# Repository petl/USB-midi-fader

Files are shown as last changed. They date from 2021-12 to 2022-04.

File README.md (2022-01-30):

# USB-midi-fader
A simple to build USB midi controller.

Please note that the V2 of this controller can be bought as a complete set with better components, a pre assembled PCB and much more on my tindie: https://www.tindie.com/products/petl/midi-fader-controller-usb-c/

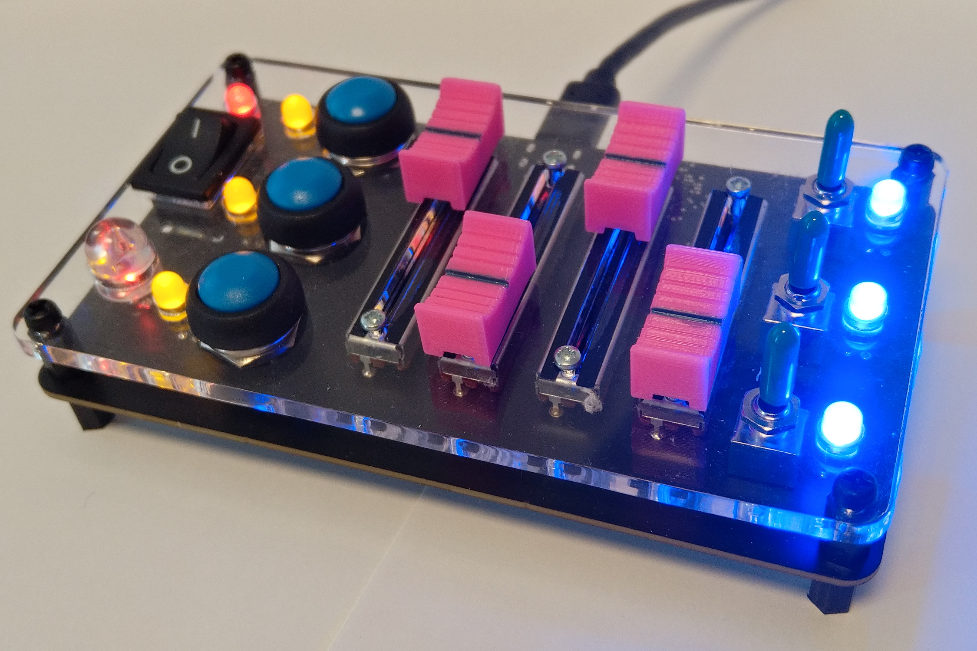
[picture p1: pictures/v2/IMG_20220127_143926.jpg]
<p align="right"> Fader v2.</p>

If you're not interested in that, you can still make everything yourself, all the files (v1 & v2) are open source!

<p><p><h2> Motivation </h2> </p>
I have been browsing the net for an easy to use USB Midi controller which can be used with my mixing software  <a href='https://mixxx.org'>Mixxx</a>  to be able to mix podcasts on the go. Initially I wanted to buy an off the shelf product from Korg, the <a href='https://www.korg.com/de/products/computergear/nanokontrol2/'>Nanokontrol 2</a>, but they raised their prices to 69€. That's honestly not a lot for a product this powerful, but what if I tell you that I can make it at home for less? Let's say 54€ less? Yes, I paid 15€ for the stuff (without the Arduino clone i already had). Read it on my blog <a href='https://quiescentcurrent.com/blog/post.php?p_id=69'>here</a>.<br>

<p align="right"> Finished fader.</p>

<p><h2> Specifications </h2> </p>

The has a few interesting features, mainly that it can easily be programmed in the Arduino IDE. The LEDs are all separately addressable, which makes them writeable via the computer interface. All switches including the big red one are also connected to the <a href='https://www.tindie.com/products/petl/breadboard-arduino-uno-clone//'>Breadboard Arduino clone</a>.  It doesn't need an external power supply or anything else.  
<ul>
<li>4x 30mm Slider Potentiometers with custom knobs. </li>
<li>7x individually addressable LEDs</li>
<li>1x red/green dual color 10mm LED for RX/TX</li>
<li>1x main switch, software controlled.</li>
<li>3x buttons</li>
<li>3x DPST switches </li>
<li>micro USB to serial connection.</li>
</ul> 

<p><h2> Hardware </h2> </p>
The hardware was partly lasercut, and partly 3D printed. The lasercutter is a cheap chinese 40W one with a pair of really expensive <a href='https://www.thorlabs.com/newgrouppage9.cfm?objectgroup_id=762#2534'>thorlabs safety goggles</a>. I used 4mm acrylic glas and grey PLA filament. The fader knobs are pink PLA. <br>
In total the stuff cost me around 15€, including the Arduino clone it would be around 33€. <br><br>

<table class="tg">
<thead>
  <tr>
    <th class="tg-qd3n">Name</th>
    <th class="tg-qd3n">Pcs</th>
    <th class="tg-qd3n">Price</th>
    <th class="tg-78by">Total</th>
    <th class="tg-78by">URL</th>
  </tr>
</thead>
<tbody>
  <tr>
    <td class="tg-lboi">Switch DPST</td>
    <td class="tg-lboi">4</td>
    <td class="tg-lboi">1.29</td>
    <td class="tg-cly1">5.16</td>
    <td class="tg-7h26"><a href="https://www.conrad.at/de/p/tru-components-kippschalter-250-v-ac-2-a-2-x-ein-ein-rastend-1-st-2304637.html">https://www.conrad.at/de/p/tru-components-kippschalter-250-v-ac-2-a-2-x-ein-ein-rastend-1-st-2304637.html</a></td>
  </tr>
  <tr>
    <td class="tg-lboi">Switch red</td>
    <td class="tg-lboi">1</td>
    <td class="tg-lboi">3.3</td>
    <td class="tg-cly1">3.3</td>
    <td class="tg-7h26"><a href="https://www.ebay.at/itm/312093751996">https://www.ebay.at/itm/312093751996</a></td>
  </tr>
  <tr>
    <td class="tg-lboi">Button switch</td>
    <td class="tg-lboi">3</td>
    <td class="tg-lboi">0.59</td>
    <td class="tg-cly1">1.77</td>
    <td class="tg-7h26"><a href="https://www.ebay.at/itm/223587573763">https://www.ebay.at/itm/223587573763</a></td>
  </tr>
  <tr>
    <td class="tg-lboi">Slider Potentiometer</td>
    <td class="tg-lboi">4</td>
    <td class="tg-lboi">0.89</td>
    <td class="tg-cly1">3.56</td>
    <td class="tg-7h26"><a href="https://www.conrad.at/de/p/tru-components-f3031n-schiebe-potentiometer-10-k-mono-0-1-w-linear-1-st-1567032.html">https://www.conrad.at/de/p/tru-components-f3031n-schiebe-potentiometer-10-k-mono-0-1-w-linear-1-st-1567032.html</a></td>
  </tr>
  <tr>
    <td class="tg-lboi">LED 5mm</td>
    <td class="tg-lboi">7</td>
    <td class="tg-lboi">0.02</td>
    <td class="tg-cly1">0.14</td>
    <td class="tg-7h26"><a href="https://www.ebay.at/itm/124214363745">https://www.ebay.at/itm/124214363745</a></td>
  </tr>
  <tr>
    <td class="tg-cly1">LED 10mm</td>
    <td class="tg-cly1">1</td>
    <td class="tg-cly1">1.26</td>
    <td class="tg-cly1">1.26</td>
    <td class="tg-7h26"><a href="https://www.ebay.at/itm/323443837179">https://www.ebay.at/itm/323443837179</a></td>
  </tr>
  <tr>
    <td class="tg-cly1">Resistor 220 Ohm</td>
    <td class="tg-cly1">3</td>
    <td class="tg-cly1">0.07</td>
    <td class="tg-cly1">0.21</td>
    <td class="tg-7h26"><a href="https://www.ebay.at/itm/372813822157">https://www.ebay.at/itm/372813822157</a></td>
  </tr>
  <tr>
    <td class="tg-cly1">Resistor 1k Ohm</td>
    <td class="tg-cly1">6</td>
    <td class="tg-cly1">0.07</td>
    <td class="tg-cly1">0.42</td>
    <td class="tg-7h26"><a href="https://www.ebay.at/itm/372813822157">https://www.ebay.at/itm/372813822157</a></td>
  </tr>
  <tr>
    <td class="tg-0lax">Screw M3x20 & M3 inserts</td>
    <td class="tg-0lax">4</td>
    <td class="tg-0lax"></td>
    <td class="tg-0lax"></td>
    <td class="tg-0lax"></td>
  </tr>
  <tr>
    <td class="tg-0lax">Screw M2.5x6</td>
    <td class="tg-0lax">8</td>
    <td class="tg-0lax"></td>
    <td class="tg-0lax"></td>
    <td class="tg-0lax"></td>
  </tr>
  <tr>
    <td class="tg-cly1">Breadboard BB UNO</td>
    <td class="tg-cly1">1</td>
    <td class="tg-cly1">18</td>
    <td class="tg-cly1">18</td>
    <td class="tg-7h26"><a href="https://www.tindie.com/products/petl/breadboard-arduino-uno-clone/">https://www.tindie.com/products/petl/breadboard-arduino-uno-clone/</a></td>
  </tr>
</tbody>
</table><p align="right"> Bill of materials. </p>

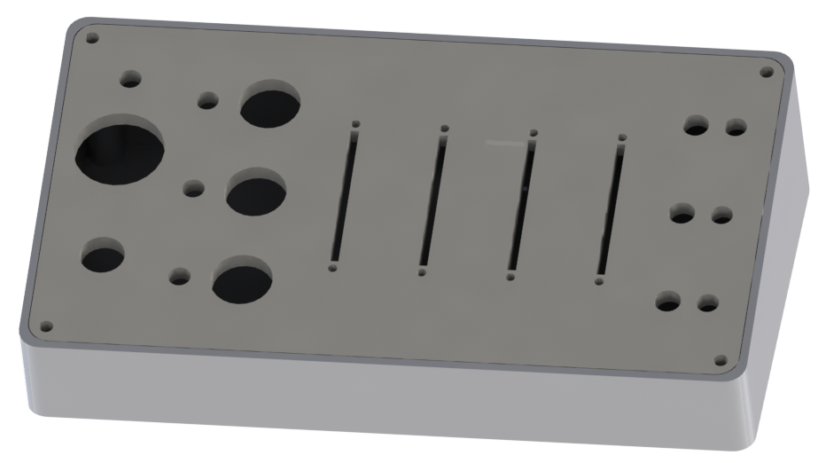
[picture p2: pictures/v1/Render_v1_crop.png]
<p align="right">Rendering of the case and frontplate.</p>

<h3>Frontplate:</h3>

Luckily SolidWorks can directly export to a .dxf file. This format can be read via the K40 Whisperer software and cut on the lasercutter. I avoided adding any markings on the acrylic, because it looks cleaner this way. Also I couldn't think of anything useful to add, feel free to let me know. 

<p align="right"> Lasercut frontplate.</p>

The parts all fit perfectly, the LEDs are glued in with a drop off general purpose glue. Don't use Cyanoacrylate glue, it will destroy the acrylic. 

<h3>Case:</h3>
I had to print the case in two parts as my 3D printer would have been too small otherwise. I glued it together with Cyanoacrylate glue, which works surprisingly well. It has four pillars for the M3 inserts, which can be put in with a soldering iron and a steady hand. The opening in the back perfectly fits the micro USB port. the print is quite easy to do for most 3D printers and should be doable with almost all materials. I used colorFabb PLA, grey for the case and pink for the sliders. The sliders have a black stripe in the middle as it looks nice. On the bottom are four 11mm diameter cutouts for 10x4mm rubber feet, this gives the case a better feeling. <br><br>

<p align="right"> 3D printed case with Arduino clone already mounted.</p>

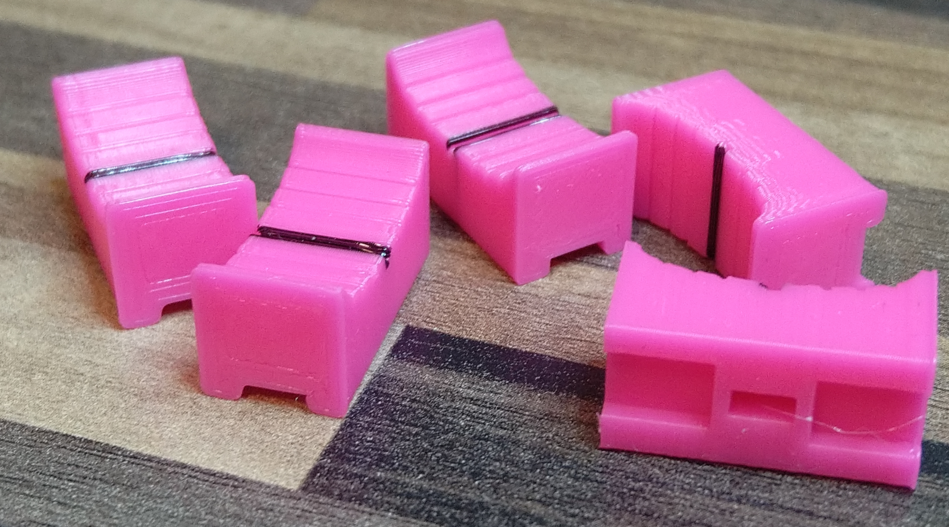
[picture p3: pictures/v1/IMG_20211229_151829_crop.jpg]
<p align="right"> Pink sliders with black stripe.</p>

<p align="right"> Rubber feet on the bottom of the case.</p>

<h3>Schematics:</h3>
All of the connections were soldered directly onto the parts. The current limiting resistors are on the back of the LEDs, the blue ones got 220 Ohm due to their higher forward voltage, the others 1k Ohm. There is a ground rails going all around the back and the sliders also have +5V connected on top. The Arduino clone I had lying around was a perfect fit, as it has all IOs in two rows. <br><br>

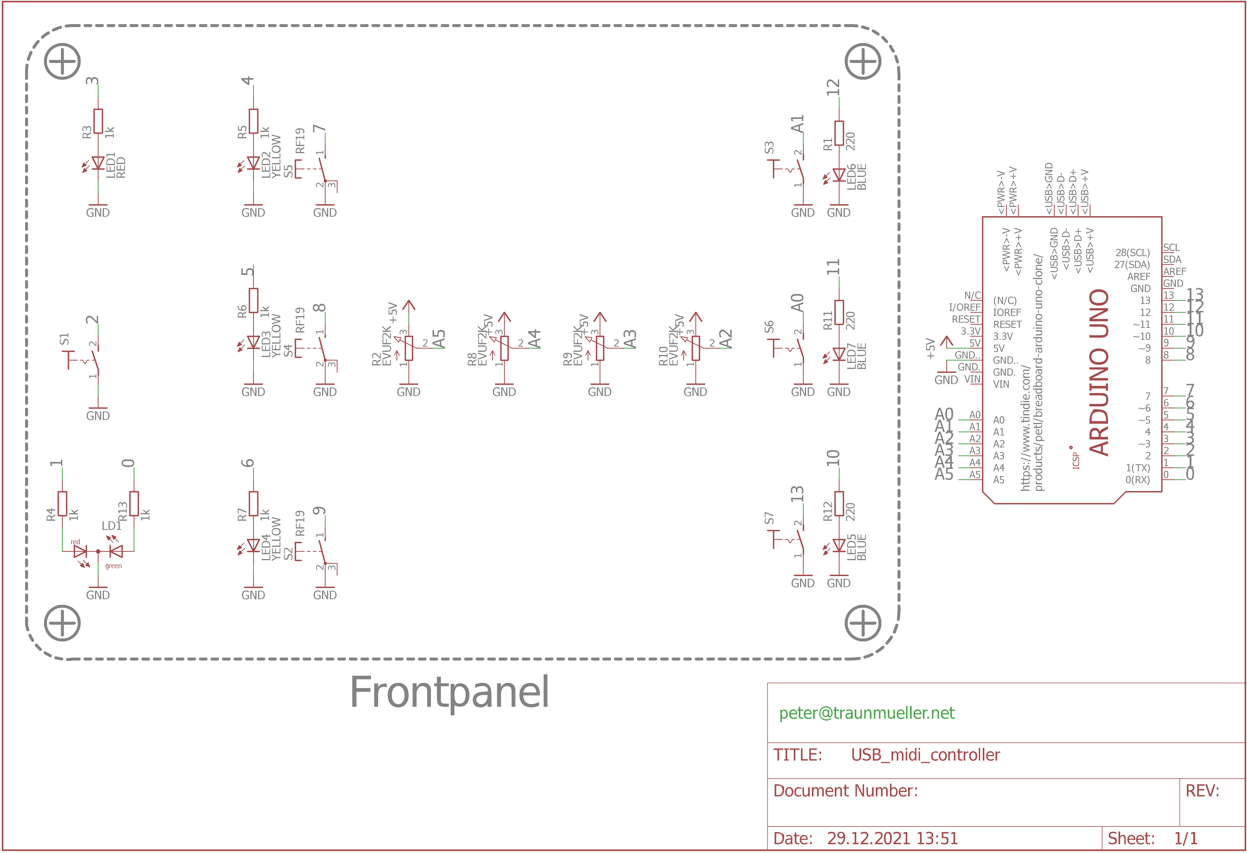
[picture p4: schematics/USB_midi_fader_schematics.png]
<p align="right"> Schematics.</p>

<p><h2> Software </h2> </p>

As most Arduino clones don't have a dedicated USB microcontroller, I opted for a virtual Midi port. This means that the CH340 on my clone opens a virtual COM port on my machine and an additional software converts it into a Midi port. The software used for this is called <a href='https://projectgus.github.io/hairless-midiserial/ '>hairless Midi</a> and works like a charm directly out of the box. It has a Windows, Mac and Linux version, so no stress there. 

<h3>Code:</h3>
Coding wise this project is as simple as it gets. I wrote it as a long loop so it can be easily modified also by non coding people. Just take a look at the <a href='https://github.com/petl/USB-midi-fader '>github</a> page and scroll through. 

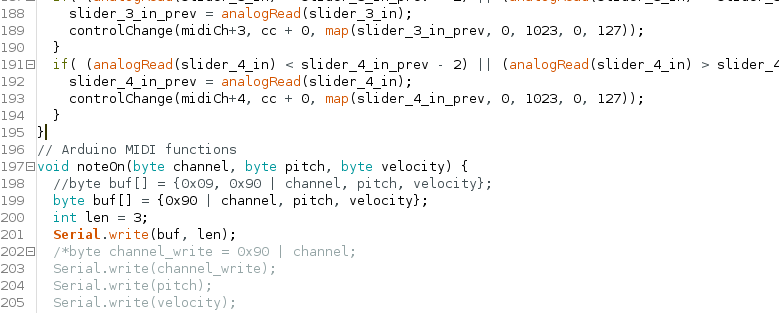
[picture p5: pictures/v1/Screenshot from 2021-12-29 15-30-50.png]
<p align="right"> Screenshot of the code.</p>

<h3>Mixxx:</h3>

Mixxx is quite chill about different midi inputs. I used the learning wizard to choose the controls I wanted to be controlled by the USB midi controller. It took a couple of minutes to have all the buttons, switches and sliders mapped onto the right elements. Afterwards everything worked like a charm and Mixxx saved my settings in a nice file. <br><br>

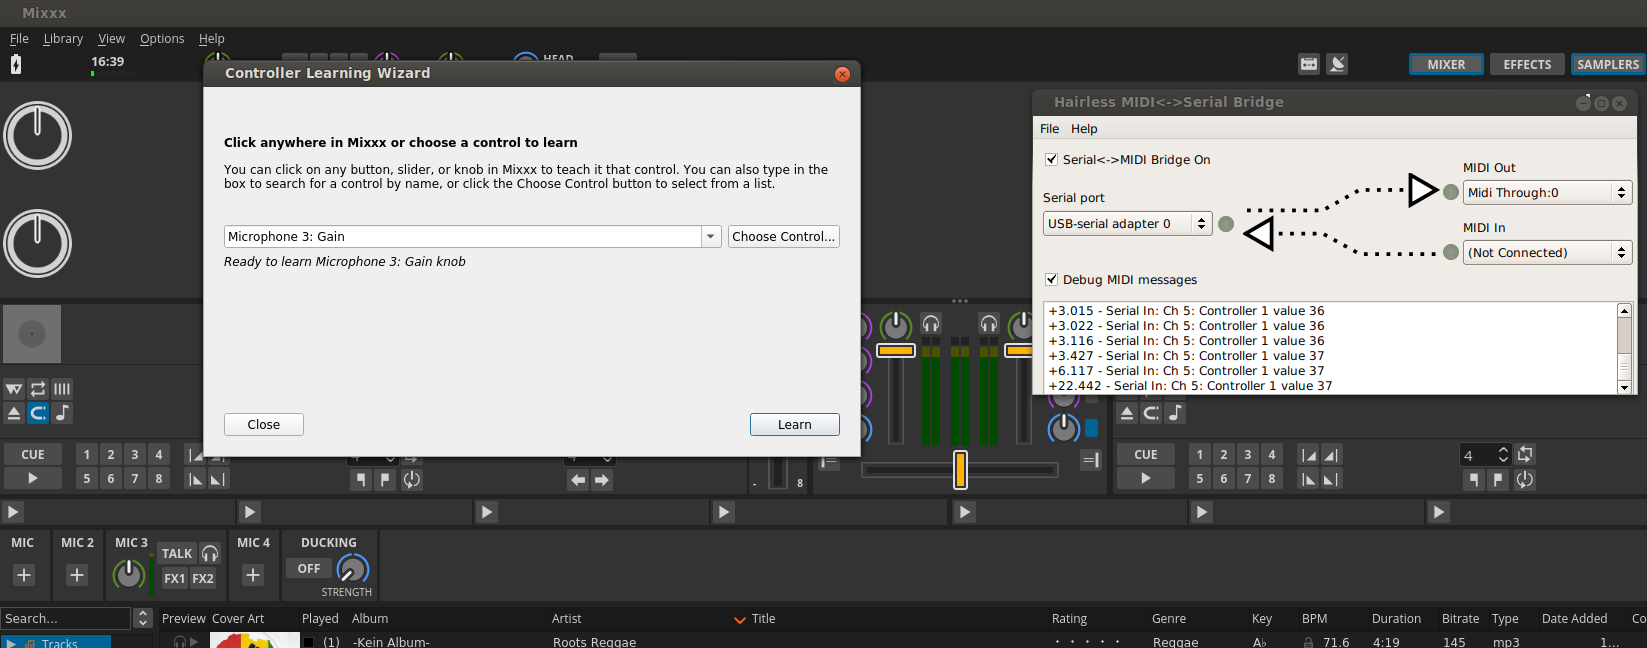
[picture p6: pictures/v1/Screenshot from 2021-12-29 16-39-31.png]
<p align="right"> Screenshot with Mixxx and hairless midi.</p>

<p><h2> Conclusion </h2> </p>So that's that, I hope this guide didn't get too long. The text is copied from my blog <a href='https://quiescentcurrent.com/blog/post.php?p_id=69'>here</a>. Thanks to the original <a href='https://www.instructables.com/DIY-USB-Midi-Controller-With-Arduino-a-Beginners-G/'>tutorial</a> I was loosely following.  If you have any questions or feedback just write a message or leave a comment on the <a href='https://quiescentcurrent.com/blog/post.php?p_id=69'>blog post</a>. <3 <br><br>

<p align="right">Less glamorous shot of the final product.</p>
</p>

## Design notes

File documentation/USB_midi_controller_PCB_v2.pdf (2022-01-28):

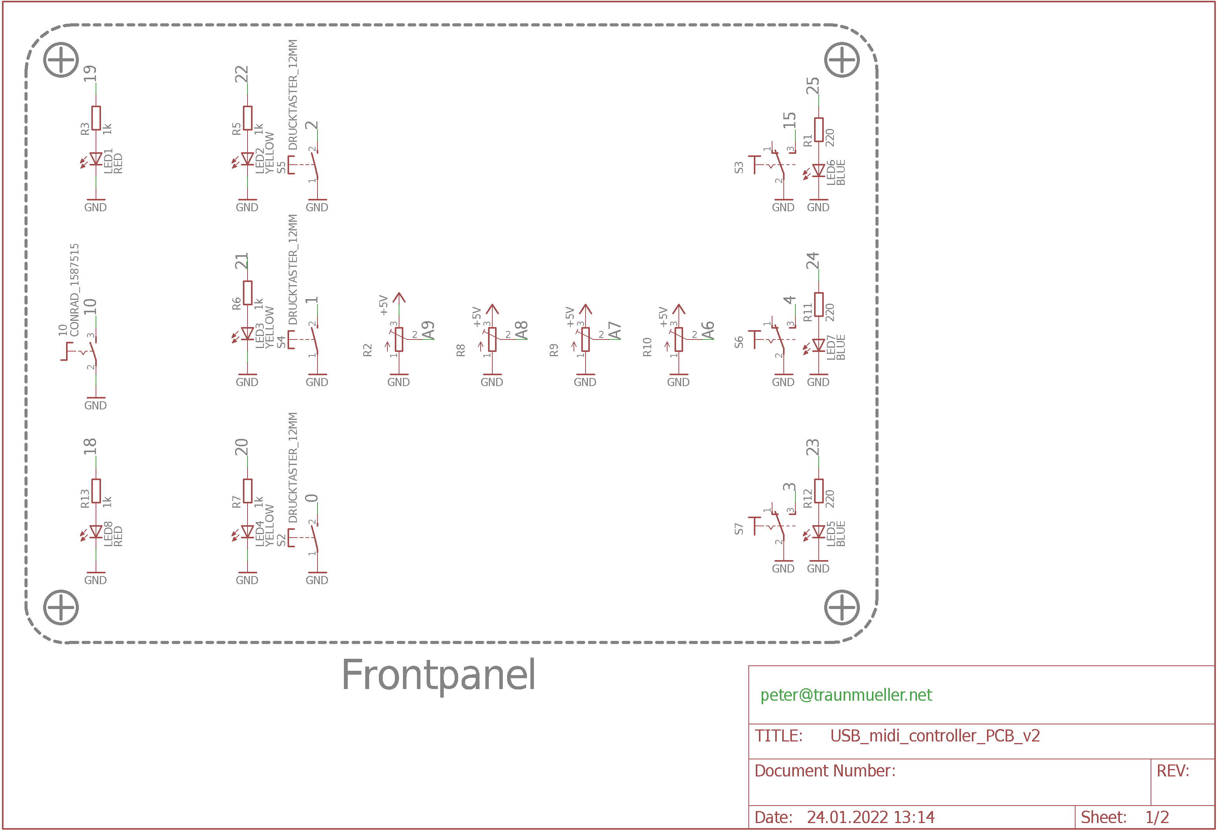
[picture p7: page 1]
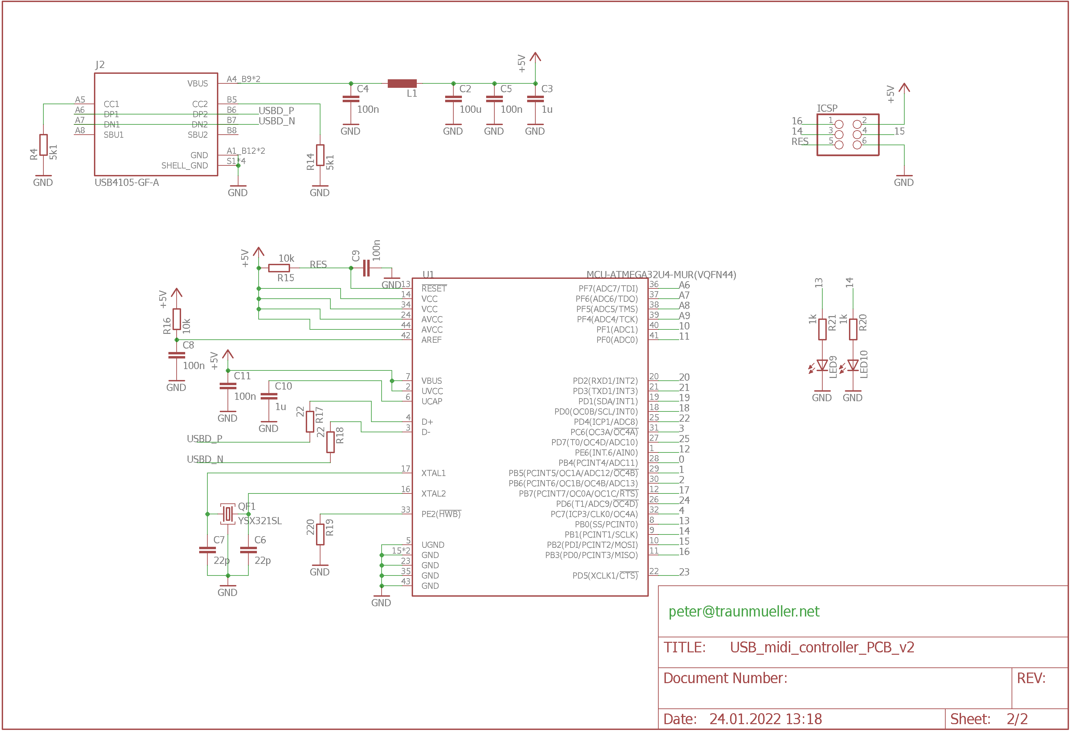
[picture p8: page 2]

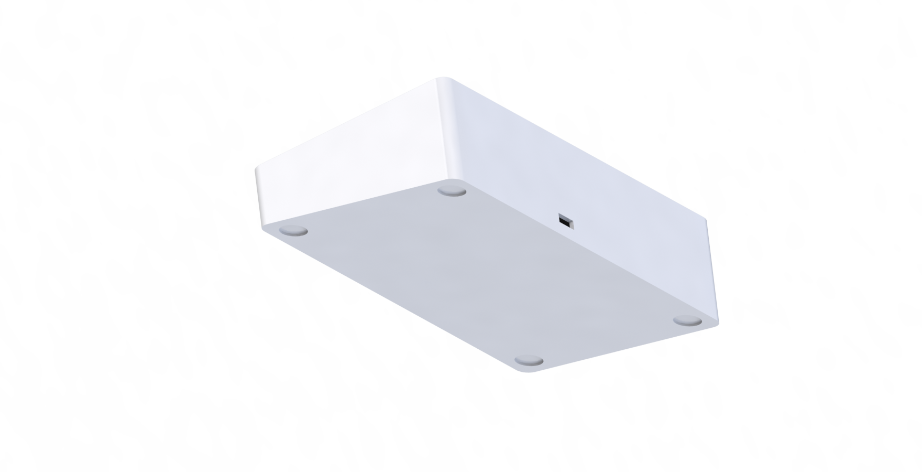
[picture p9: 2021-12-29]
mechanics/Render2_v1.png

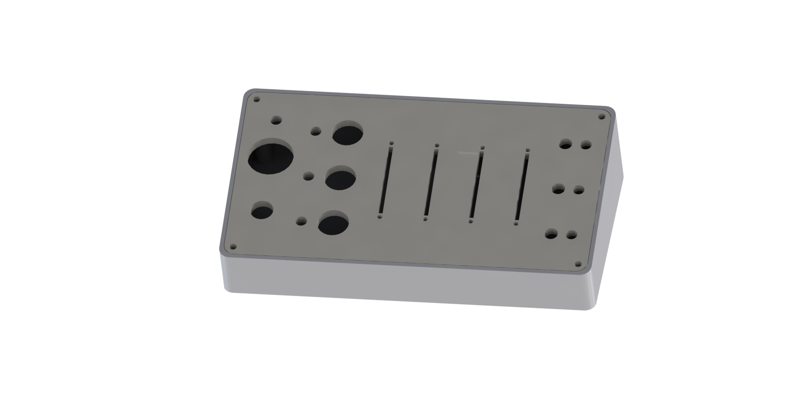
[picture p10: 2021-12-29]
mechanics/Render_v1.png

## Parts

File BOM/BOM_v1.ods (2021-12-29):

Name | Pcs | Price | Total | URL
Switch DPST | 4 | 1.29 | 5.16 | https://www.conrad.at/de/p/tru-components-kippschalter-250-v-ac-2-a-2-x-ein-ein-rastend-1-st-2304637.html
Switch red | 1 | 3.3 | 3.3 | https://www.ebay.at/itm/312093751996
Button switch | 3 | 0.59 | 1.77 | https://www.ebay.at/itm/223587573763
Slider Potentiometer | 4 | 0.89 | 3.56 | https://www.conrad.at/de/p/tru-components-f3031n-schiebe-potentiometer-10-k-mono-0-1-w-linear-1-st-1567032.html
LED 5mm | 7 | 0.02 | 0.14 | https://www.ebay.at/itm/124214363745
LED 10mm | 1 | 1.26 | 1.26 | https://www.ebay.at/itm/323443837179
Resistor 220 Ohm | 3 | 0.07 | 0.21 | https://www.ebay.at/itm/372813822157
Resistor 1k Ohm | 6 | 0.07 | 0.42 | https://www.ebay.at/itm/372813822157
Breadboard BB UNO | 1 | 18 | 18 | https://www.tindie.com/products/petl/breadboard-arduino-uno-clone/
Price Total € |  |  | 33.82

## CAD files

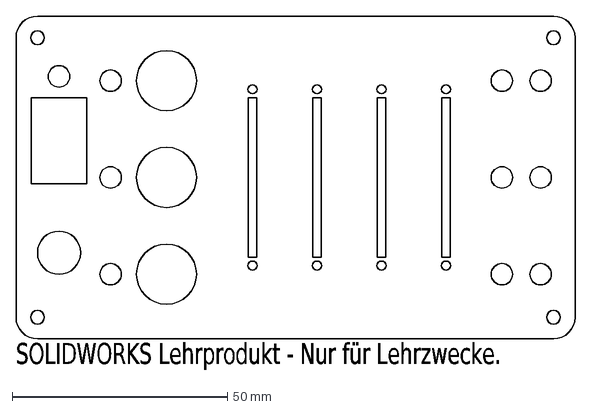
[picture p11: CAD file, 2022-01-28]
mechanics/Frontplate_PCB_v2.dxf
SOLIDWORKS Lehrprodukt - Nur für Lehrzwecke.

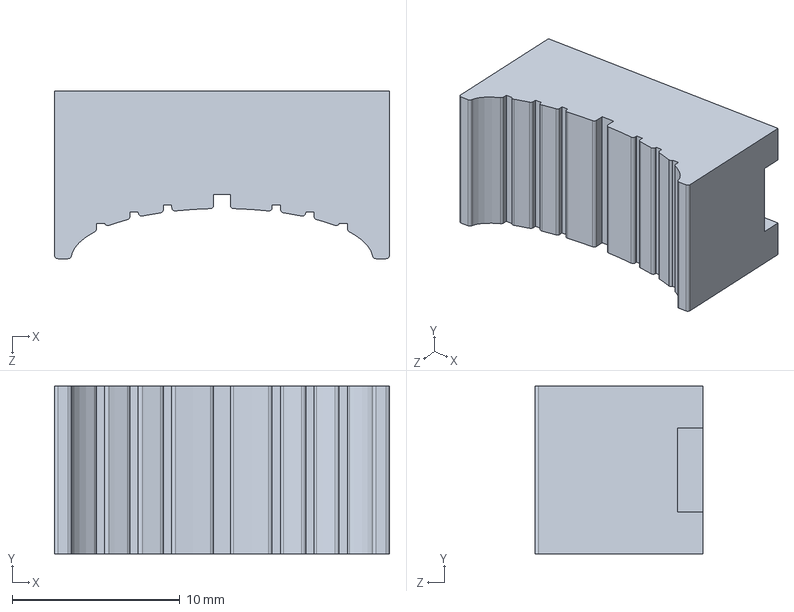
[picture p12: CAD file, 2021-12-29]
mechanics/Slider_Knob.SLDPRT
20.0 x 10.0 x 10.0 mm

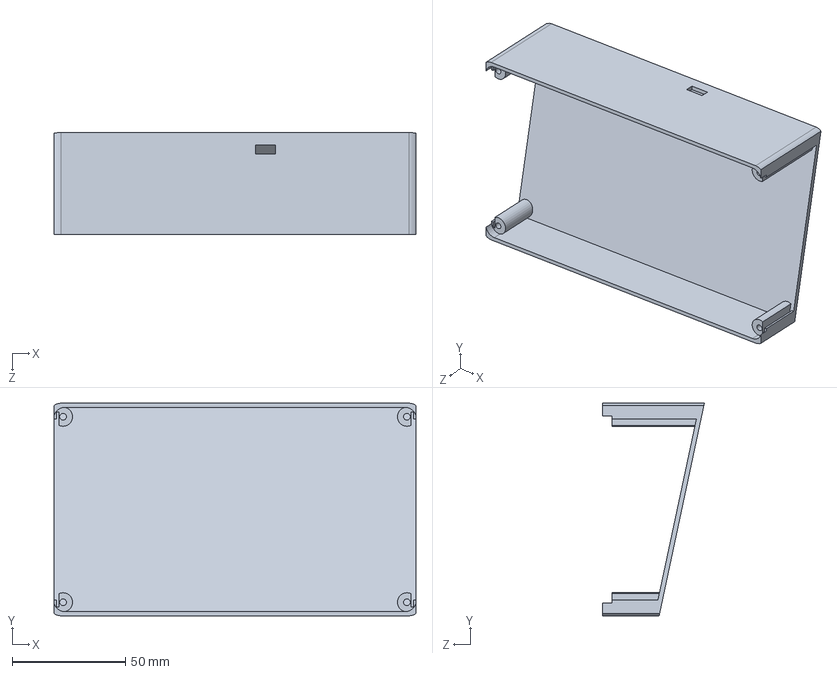
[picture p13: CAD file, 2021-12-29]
mechanics/USB_midi_fader_box_v2.SLDPRT
160.0 x 94.0 x 45.0 mm

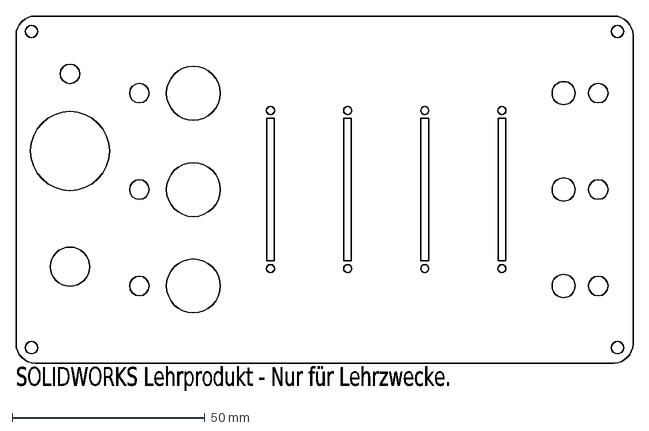
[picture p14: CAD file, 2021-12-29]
mechanics/Frontplate_v1.DXF
SOLIDWORKS Lehrprodukt - Nur für Lehrzwecke.

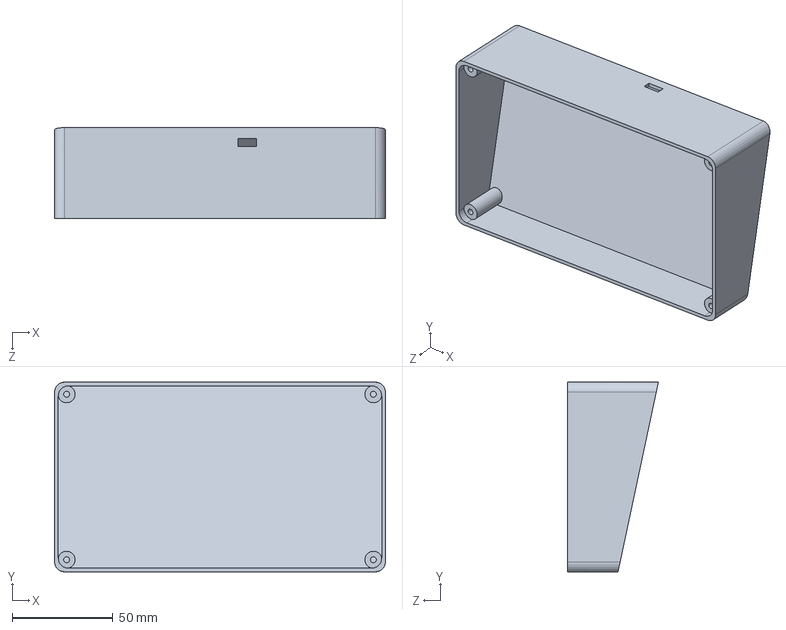
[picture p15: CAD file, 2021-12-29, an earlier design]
mechanics/USB_midi_fader_box_v1.SLDPRT
164.0 x 94.0 x 45.0 mm

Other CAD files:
mechanics/Slider_Knob.STL
mechanics/USB_midi_fader_box_v1.STL
mechanics/USB_midi_fader_box_v2.STL

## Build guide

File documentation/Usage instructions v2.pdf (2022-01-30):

## Usage instructions

Please download the soldering instructions from:

https://www.tindie.com/products/petl/midi-fader-controller-usb-c/ Additional information:
This USB C based controller is the perfect solution for Podcasting, Live streaming,

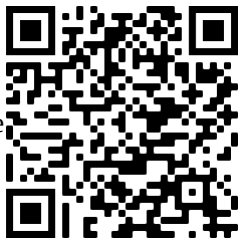
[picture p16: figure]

Recording, Mixing and many other things like lighting control that require a software solution for fading and switching. All faders and switches can be used as custom
controls in many different software tools like Mixxx, MIDI Mixer, Ableton and many
more.
The switches and buttons all are heavy duty and have a really awesome clicky feeling to them. This makes the controls blindly usable due to their positioning and haptic feedback. LEDs light up with their corresponding switch/button by default to indicate them being turned on/pressed.
All the code is open source and can be individually customized. Each element has a dedicated input or output from the microcontroller and can be arbitrarily controlled. There are two debug LEDs on the back to indicate operation.
- 4 Faders
- 3 Push buttons
- 3 Switches
- 1 Rocker switch
- 7 5mm LEDs
- 1 10mm LED
In term of size, the fully assembled USB controller is 135x75x55mm (5.3x2.9x2.1 inch)
The USB MIDI fader controller has been tested to be working out of the box with the following configurations:
- Macbook mac OS - Studio one
- Windows 7 - Sunlite suite
- Ubuntu Linux - Mixxx
After USB connection is established, the unit shows up as a dedicated MIDI device. The operating systems tested (Windows, mac OS, Ubuntu) didn't need a special installation or driver installed. No dedicated power supply is needed, all necessary power is supplied over the USB C port.
The item still is a prototype. It is working as intended, but funny quirks and other things are possible. It is not certified and only suited for prototyping.

If you have any questions, just shoot me a message!

Have fun tinkering and thanks for buying!

https://www.tindie.com/stores/petl/ | MIDI fader controller USB C v2

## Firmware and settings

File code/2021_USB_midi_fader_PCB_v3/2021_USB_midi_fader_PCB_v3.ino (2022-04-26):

/*
   MIDI controller
   Features 4 sliders, 3 button, 4 switches, and a couple of LEDs
   Runs on an ATmega32U4 with the mattairTech stuff

   12.2021, 2.2022, 4.2022
   peter@traunmueller.net

   Thanks to for the tutorial: https://www.instructables.com/DIY-USB-Midi-Controller-With-Arduino-a-Beginners-G/

*/
//uint8_t USB_EP_SIZE = 64

#include "MIDIUSB.h"


//Define the pinout and variables to store the previous values
// Could have done this in an array, but i think it's easier to understand like this
#define button_main_in  10 // big sqare button, left side
int button_main_in_prev = 0 ;
#define button_main_out  19

#define button_top_in  2 //button row in the middle left
int button_top_in_prev = 0 ;
#define button_top_out  22

#define button_middle_in  1 //button row in the middle left
int button_middle_in_prev = 0 ;
#define button_middle_out  21

#define button_bottom_in  0 //button row in the middle left
int button_bottom_in_prev = 0 ;
#define button_bottom_out  20

#define switch_top_in  15 //switch row on the right
int switch_top_in_prev = 0 ;
#define switch_top_out  25

#define switch_middle_in  4//switch row on the right
int switch_middle_in_prev = 0 ;
#define switch_middle_out  24

#define switch_bottom_in  3//switch row on the right
int switch_bottom_in_prev = 0 ;
#define switch_bottom_out 23

#define slider_1_in  A9 // sliders are numbered LEFT to RIGHT
int slider_1_in_prev = 0 ;
#define slider_2_in  A8
int slider_2_in_prev = 0 ;
#define slider_3_in  A7
int slider_3_in_prev = 0 ;
#define slider_4_in  A6 // this is the rightmost slider
int slider_4_in_prev = 0 ;

//#define led_green_out  0 // Don't use this as outputs, they are connected to RX/TX!
#define led_red_out  18 //  10mm red LED left bottom, indicate RX/TX!

#define led_blue1_out  13 //  small blue LED for debugging
#define led_blue2_out  14 //  small blue LED for debugging



// MIDI Assignments
byte midiCh = 1; //* MIDI channel to be used
byte note = 36; //* Lowest note to be used; 36 = C2; 60 = Middle C
byte cc = 1; //* Lowest MIDI CC to be used



void setup() {
  pinMode(led_blue1_out ,OUTPUT);
  pinMode(led_blue2_out ,OUTPUT);
  digitalWrite(led_blue2_out, LOW);
  digitalWrite(led_blue1_out, HIGH);
  
  //hairless midi uses 115200 by default
  //while(!Serial);//wait for serial to become available
  //Serial.begin(115200);

  //we have to enable pullups for our inputs, as they would be floating otherwise
  pinMode(button_main_in , INPUT_PULLUP);
  pinMode(button_middle_in , INPUT_PULLUP);
  pinMode(button_bottom_in , INPUT_PULLUP);
  pinMode(button_top_in , INPUT_PULLUP);
  pinMode(switch_top_in , INPUT_PULLUP);
  pinMode(switch_middle_in , INPUT_PULLUP);
  pinMode(switch_bottom_in , INPUT_PULLUP);

  pinMode(button_main_out , OUTPUT);
  pinMode(button_middle_out , OUTPUT);
  pinMode(button_bottom_out , OUTPUT);
  pinMode(button_top_out , OUTPUT);
  pinMode(switch_top_out , OUTPUT);
  pinMode(switch_middle_out , OUTPUT);
  pinMode(switch_bottom_out , OUTPUT);
  //set the switch outputs to high, so they initialize correctly
  digitalWrite(button_top_out, HIGH);
  digitalWrite(switch_top_out, HIGH);
  digitalWrite(switch_middle_out, HIGH);
  digitalWrite(switch_bottom_out, HIGH);
  //pinMode(led_green_out ,OUTPUT);
  pinMode(led_red_out ,OUTPUT);

  digitalWrite(led_blue2_out, HIGH);

}

void loop() {
  //in here we just check if something has changed repeatedly

  //BUTTONS
  if (digitalRead(button_main_in) != button_main_in_prev) {
    if (digitalRead(button_main_in) == HIGH) {
      noteOn(midiCh + 0, note + 0, 0);
      digitalWrite(button_main_out, LOW);
      button_main_in_prev = 1;
    }
    else {
      noteOn(midiCh + 0, note + 0, 127);
      digitalWrite(button_main_out, HIGH);
      button_main_in_prev = 0;
    }
  }
  if (digitalRead(button_middle_in) != button_middle_in_prev) {
    if (digitalRead(button_middle_in) == HIGH) {
      noteOn(midiCh + 0, note + 1, 0);
      digitalWrite(button_middle_out, LOW);
      button_middle_in_prev = 1;
    }
    else {
      noteOn(midiCh + 0, note + 1, 127);
      digitalWrite(button_middle_out, HIGH);
      button_middle_in_prev = 0;
    }
  }
  if (digitalRead(button_bottom_in) != button_bottom_in_prev) {
    if (digitalRead(button_bottom_in) == HIGH) {
      noteOn(midiCh + 0, note + 2, 0);
      digitalWrite(button_bottom_out, LOW);
      button_bottom_in_prev = 1;
    }
    else {
      noteOn(midiCh + 0, note + 2, 127);
      digitalWrite(button_bottom_out, HIGH);
      button_bottom_in_prev = 0;
    }
  }

  //SWITCHES
  if (digitalRead(button_top_in) != button_top_in_prev) {
    if (digitalRead(button_top_in) == HIGH) {
      noteOn(midiCh + 0, note + 3, 0);
      digitalWrite(button_top_out, LOW);
      button_top_in_prev = 1;
    }
    else {
      noteOn(midiCh + 0, note + 3, 127);
      digitalWrite(button_top_out, HIGH);
      button_top_in_prev = 0;
    }
  }
  if (digitalRead(switch_top_in) != switch_top_in_prev) {
    if (digitalRead(switch_top_in) == HIGH) {
      noteOn(midiCh + 0, note + 4, 0);
      digitalWrite(switch_top_out, LOW);
      switch_top_in_prev = 1;
    }
    else {
      noteOn(midiCh + 0, note + 4, 127);
      digitalWrite(switch_top_out, HIGH);
      switch_top_in_prev = 0;
    }
  }
  if (digitalRead(switch_middle_in) != switch_middle_in_prev) {
    if (digitalRead(switch_middle_in) == HIGH) {
      noteOn(midiCh + 0, note + 5, 0);
      digitalWrite(switch_middle_out, LOW);
      switch_middle_in_prev = 1;
    }
    else {
      noteOn(midiCh + 0, note + 5, 127);
      digitalWrite(switch_middle_out, HIGH);
      switch_middle_in_prev = 0;
    }
  }
  if (digitalRead(switch_bottom_in) != switch_bottom_in_prev) {
    if (digitalRead(switch_bottom_in) == HIGH) {
      noteOn(midiCh + 0, note + 6, 0);
      digitalWrite(switch_bottom_out, LOW);
      switch_bottom_in_prev = 1;
    }
    else {
      noteOn(midiCh + 0, note + 6, 127);
      digitalWrite(switch_bottom_out, HIGH);
      switch_bottom_in_prev = 0;
    }
  }

  //POTENTIOMETERS
  if ( (analogRead(slider_1_in) < slider_1_in_prev - 2) || (analogRead(slider_1_in) > slider_1_in_prev + 2)) {
    slider_1_in_prev = analogRead(slider_1_in);
    controlChange(midiCh + 1, cc + 0, map(slider_1_in_prev, 0, 1023, 127, 0));
  }
  if ( (analogRead(slider_2_in) < slider_2_in_prev - 2) || (analogRead(slider_2_in) > slider_2_in_prev + 2)) {
    slider_2_in_prev = analogRead(slider_2_in);
    controlChange(midiCh + 2, cc + 0, map(slider_2_in_prev, 0, 1023, 127, 0));
  }
  if ( (analogRead(slider_3_in) < slider_3_in_prev - 2) || (analogRead(slider_3_in) > slider_3_in_prev + 2)) {
    slider_3_in_prev = analogRead(slider_3_in);
    controlChange(midiCh + 3, cc + 0, map(slider_3_in_prev, 0, 1023, 127, 0));
  }
  if ( (analogRead(slider_4_in) < slider_4_in_prev - 2) || (analogRead(slider_4_in) > slider_4_in_prev + 2)) {
    slider_4_in_prev = analogRead(slider_4_in);
    controlChange(midiCh + 4, cc + 0, map(slider_4_in_prev, 0, 1023, 127, 0));
  }
}
// Arduino MIDI functions
/*
void noteOn(byte channel, byte pitch, byte velocity) {
  //byte buf[] = {0x09, 0x90 | channel, pitch, velocity};
  byte buf[] = {0x90 | channel, pitch, velocity};
  int len = 3;
  digitalWrite(led_red_out, HIGH);
  Serial.write(buf, len);
  digitalWrite(led_red_out, LOW);

}

void controlChange(byte channel, byte control, byte value) {
  //byte buf[] = {0x0B, 0xB0 | channel, control, value};
  byte buf[] = {0xB0 | channel, control, value};
  int len = 3;
  digitalWrite(led_red_out, HIGH);
  Serial.write(buf, len);
  digitalWrite(led_red_out, LOW);
}
*/

void controlChange(byte channel, byte control, byte value) {
  //byte buf[] = {0x0B, 0xB0 | channel, control, value};
  //byte buf[] = {0xB0 , channel, control, value};
  midiEventPacket_t event = {0x0B, 0xB0 | channel, control, value};
  int len = 3;
  digitalWrite(led_red_out, HIGH);
  MidiUSB.sendMIDI(event);
  MidiUSB.flush();
  digitalWrite(led_red_out, LOW);
}
void noteOn(byte channel, byte pitch, byte velocity)  {
  //byte buf[] = {0x90 , channel, pitch, velocity};
  //{0x09, 0x90, pitch, 127})
  midiEventPacket_t event = {0x0B, 0xB0 | channel, pitch, velocity};
  digitalWrite(led_red_out, HIGH);
  MidiUSB.sendMIDI(event);
  MidiUSB.flush();
  digitalWrite(led_red_out, LOW);
}

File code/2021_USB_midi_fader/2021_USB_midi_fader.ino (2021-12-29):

/*
 * MIDI controller
 * Features 4 sliders, 3 button, 4 switches, and a couple of LEDs 
 * to be used with hairless MIDI
 * 
 * 12.2021
 * peter@traunmueller.net
 * 
 * Thanks to for the tutorial: https://www.instructables.com/DIY-USB-Midi-Controller-With-Arduino-a-Beginners-G/
 * 
 */


//Define the pinout and variables to store the previous values
// Could have done this in an array, but i think it's easier to understand like this
#define button_red_in  7 // big red button, left side
int button_red_in_prev = 0 ; 
#define button_red_out  4

#define switch_red_in  2 //button row in the middle left
int switch_red_in_prev = 0 ; 
#define switch_red_out  3

#define button_green_in  8 //button row in the middle left
int button_green_in_prev = 0 ; 
#define button_green_out  5

#define button_blue_in  9 //button row in the middle left
int button_blue_in_prev = 0 ; 
#define button_blue_out  6

#define switch_top_in  A1 //switch row on the right
int switch_top_in_prev = 0 ; 
#define switch_top_out  12

#define switch_middle_in  A0//switch row on the right
int switch_middle_in_prev = 0 ; 
#define switch_middle_out  11

#define switch_bottom_in  13//switch row on the right
int switch_bottom_in_prev = 0 ; 
#define switch_bottom_out 10

#define slider_1_in  A5 // sliders are numbered LEFT to RIGHT
int slider_1_in_prev = 0 ; 
#define slider_2_in  A4
int slider_2_in_prev = 0 ; 
#define slider_3_in  A3
int slider_3_in_prev = 0 ; 
#define slider_4_in  A2 // this is the rightmost slider
int slider_4_in_prev = 0 ; 

#define led_green_out  0 // Don't use this as outputs, they are connected to RX/TX!
#define led_red_out  1  //  Don't use this as outputs, they are connected to RX/TX!



// MIDI Assignments 
byte midiCh = 1; //* MIDI channel to be used
byte note = 36; //* Lowest note to be used; 36 = C2; 60 = Middle C
byte cc = 1; //* Lowest MIDI CC to be used



void setup() {
  //hairless midi uses 115200 by default
  Serial.begin(115200);

  //we have to enable pullups for our inputs, as they would be floating otherwise
  pinMode(button_red_in ,INPUT_PULLUP);
  pinMode(button_green_in ,INPUT_PULLUP);
  pinMode(button_blue_in ,INPUT_PULLUP);
  pinMode(switch_red_in ,INPUT_PULLUP);
  pinMode(switch_top_in ,INPUT_PULLUP);
  pinMode(switch_middle_in ,INPUT_PULLUP);
  pinMode(switch_bottom_in ,INPUT_PULLUP);

  pinMode(button_red_out ,OUTPUT);
  pinMode(button_green_out ,OUTPUT);
  pinMode(button_blue_out ,OUTPUT);
  pinMode(switch_red_out ,OUTPUT);
  pinMode(switch_top_out ,OUTPUT);
  pinMode(switch_middle_out ,OUTPUT);
  pinMode(switch_bottom_out ,OUTPUT);
  //set the switch outputs to high, so they initialize correctly 
  digitalWrite(switch_red_out, HIGH);
  digitalWrite(switch_top_out, HIGH);
  digitalWrite(switch_middle_out, HIGH);
  digitalWrite(switch_bottom_out, HIGH);
  //pinMode(led_green_out ,OUTPUT);
  //pinMode(led_red_out ,OUTPUT);

}

void loop() {
  //in here we just check if something has changed repeatedly
  
  //BUTTONS
  if(digitalRead(button_red_in) != button_red_in_prev){
    if(digitalRead(button_red_in) == HIGH){
      noteOn(midiCh+0, note + 0, 127);
      digitalWrite(button_red_out, LOW);
      button_red_in_prev = 1;
    }
    else{
      noteOn(midiCh+0, note + 0, 0);
      digitalWrite(button_red_out, HIGH);
      button_red_in_prev = 0;
    }
  }
  if(digitalRead(button_green_in) != button_green_in_prev){
    if(digitalRead(button_green_in) == HIGH){
      noteOn(midiCh+0, note + 1, 127);
      digitalWrite(button_green_out, LOW);
      button_green_in_prev = 1;
    }
    else{
      noteOn(midiCh+0, note + 1, 0);
      digitalWrite(button_green_out, HIGH);
      button_green_in_prev = 0;
    }
  }
  if(digitalRead(button_blue_in) != button_blue_in_prev){
    if(digitalRead(button_blue_in) == HIGH){
      noteOn(midiCh+0, note + 2, 127);
      digitalWrite(button_blue_out, LOW);
      button_blue_in_prev = 1;
    }
    else{
      noteOn(midiCh+0, note + 2, 0);
      digitalWrite(button_blue_out, HIGH);
      button_blue_in_prev = 0;
    }
  }

  //SWITCHES
  if(digitalRead(switch_red_in) != switch_red_in_prev){
    if(digitalRead(switch_red_in) == HIGH){
      noteOn(midiCh+0, note + 3, 127);
      digitalWrite(switch_red_out, LOW);
      switch_red_in_prev = 1;
    }
    else{
      noteOn(midiCh+0, note + 3, 0);
      digitalWrite(switch_red_out, HIGH);
      switch_red_in_prev = 0;
    }
  }
  if(digitalRead(switch_top_in) != switch_top_in_prev){
    if(digitalRead(switch_top_in) == HIGH){
      noteOn(midiCh+0, note + 4, 127);
      digitalWrite(switch_top_out, LOW);
      switch_top_in_prev = 1;
    }
    else{
      noteOn(midiCh+0, note + 4, 0);
      digitalWrite(switch_top_out, HIGH);
      switch_top_in_prev = 0;
    }
  }
  if(digitalRead(switch_middle_in) != switch_middle_in_prev){
    if(digitalRead(switch_middle_in) == HIGH){
      noteOn(midiCh+0, note + 5, 127);
      digitalWrite(switch_middle_out, LOW);
      switch_middle_in_prev = 1;
    }
    else{
      noteOn(midiCh+0, note + 5, 0);
      digitalWrite(switch_middle_out, HIGH);
      switch_middle_in_prev = 0;
    }
  }
  if(digitalRead(switch_bottom_in) != switch_bottom_in_prev){
    if(digitalRead(switch_bottom_in) == HIGH){
      noteOn(midiCh+0, note + 6, 127);
      digitalWrite(switch_bottom_out, LOW);
      switch_bottom_in_prev = 1;
    }
    else{
      noteOn(midiCh+0, note + 6, 0);
      digitalWrite(switch_bottom_out, HIGH);
      switch_bottom_in_prev = 0;
    }
  }  

  //POTENTIOMETERS
  if( (analogRead(slider_1_in) < slider_1_in_prev - 2) || (analogRead(slider_1_in) > slider_1_in_prev + 2)){
    slider_1_in_prev = analogRead(slider_1_in);
    controlChange(midiCh+1, cc + 0, map(slider_1_in_prev, 0, 1023, 0, 127));
  }
  if( (analogRead(slider_2_in) < slider_2_in_prev - 2) || (analogRead(slider_2_in) > slider_2_in_prev + 2)){
    slider_2_in_prev = analogRead(slider_2_in);
    controlChange(midiCh+2, cc + 0, map(slider_2_in_prev, 0, 1023, 0, 127));
  }
  if( (analogRead(slider_3_in) < slider_3_in_prev - 2) || (analogRead(slider_3_in) > slider_3_in_prev + 2)){
    slider_3_in_prev = analogRead(slider_3_in);
    controlChange(midiCh+3, cc + 0, map(slider_3_in_prev, 0, 1023, 0, 127));
  }
  if( (analogRead(slider_4_in) < slider_4_in_prev - 2) || (analogRead(slider_4_in) > slider_4_in_prev + 2)){
    slider_4_in_prev = analogRead(slider_4_in);
    controlChange(midiCh+4, cc + 0, map(slider_4_in_prev, 0, 1023, 0, 127));
  }
}
// Arduino MIDI functions
void noteOn(byte channel, byte pitch, byte velocity) {
  //byte buf[] = {0x09, 0x90 | channel, pitch, velocity};
  byte buf[] = {0x90 | channel, pitch, velocity};
  int len = 3;
  Serial.write(buf, len);

}
void controlChange(byte channel, byte control, byte value) {
  //byte buf[] = {0x0B, 0xB0 | channel, control, value};
  byte buf[] = {0xB0 | channel, control, value};
  int len = 3;
  Serial.write(buf, len);
}

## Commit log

2021-12-29 inital commit
    [BOM_v1.ods, Frontplate_v1.DXF, Slider_Knob.STL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]
2021-12-29 updated BOM
    [BOM_v1.ods]
2021-12-29 added slider knob design file
    [Slider_Knob.SLDPRT]
2022-01-28 v2 schematics
2022-01-28 frontplate file for v2
    [Frontplate_PCB_v2.dxf]
2022-01-30 soldering and usage instructions
